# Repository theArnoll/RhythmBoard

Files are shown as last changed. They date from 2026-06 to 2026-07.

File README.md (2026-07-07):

Logo and name

English | [繁體中文 (Traditional Chinese)](./README_zhTW.md)

An easily customizable controller for most computer rhythm games.

Suitable for multiple games, including:

| | | | |
| - | - | - | - |
| osu! | DJMAX RESPECT V | Quaver | vivid/stasis |
| Milthm | Rhythm Doctor | Sparebeat | Polylylyrhythm |
| Estella | In Falsus (theoretically) | and more | |

The overall layout and default keymap are optimized for DJMAX RESPECT V and my own key binding, but any games similar to this are supported. You only need to edit the keymap in [ZMK Studio](https://zmk.studio/) to easily optimize the Rhythmboard for the game you're playing or your preferred key bindings.

<!-- TODO: Images and photos -->

## Table of Contents

- [Table of Contents](#table-of-contents)
- [Get Started](#get-started)
  - [Install Firmware](#install-firmware)
  - [Build from hardware](#build-from-hardware)
    - [BOM](#bom)
    - [1. Prepare and Print PCB](#1-prepare-and-print-pcb)
    - [2. Solder Everything](#2-solder-everything)
    - [3. Assembly](#3-assembly)
    - [4. Install Firmware](#4-install-firmware)
- [Default keymap](#default-keymap)
  - [Customize your keymap](#customize-your-keymap)
- [TODOs](#todos)

## Get Started

[Install Firmware](#install-firmware)  
[Building your own Rhythmboard from hardware](#build-from-hardware)  
[BOM](#bom)

### Install Firmware
<details>

<summary>If you're familiar with developing RP2040 microcontrollers or Raspberry Pi Pico, click here for a shorter explanation.</summary>

1. Go to the `Actions` tab.
2. Click the latest workflow run.
3. Find the `Artifacts` section, locate `firmware`, and click the download icon on the right to download `firmware.zip`.
   **If you can't find the `Artifacts` section**, click [here](https://github.com/theArnoll/RhythmBoard/actions/runs/28886995200/artifacts/8146596750).
4. Connect your board to your computer in BOOTSEL mode (by plugging in the RP2040-Zero while holding the BOOT button).
5. Unzip the `firmware.zip` you just downloaded and find the `.uf2` file inside.
6. Drag and drop the `.uf2` file into the RP2040-Zero USB drive (likely named `RPI-RP2`), and you're good to go.

---

</details>

1. Go to the `Actions` tab.
2. Click the latest workflow run.
3. Find the `Artifacts` section, locate `firmware`, and click the download icon on the right to download `firmware.zip`.
   **If you can't find the `Artifacts` section**, click [here](https://github.com/theArnoll/RhythmBoard/actions/runs/27891480540/artifacts/7771182646).
4. Press and hold the `BOOT` button on the RP2040-Zero. **DO NOT RELEASE** it before plugging the RP2040-Zero into your computer. Once plugged in, release the button. You should see a new USB device appear on your computer, likely named `RPI-RP2`.
5. Unzip the `firmware.zip` you just downloaded, locate the `.uf2` file in the extracted folder, and drag or copy it into the USB drive that appeared in the previous step.
6. Once the copy is complete, the USB drive will automatically disconnect, and the RP2040-Zero will reboot. Your Rhythmboard is now ready to use with the latest features available.

### Build from hardware

#### BOM

- RP2040-Zero x 1
- Machined Pin Header (23 pins in total: 9 pins x 2 + 5 pins)
- Machined Female Header (23 pins in total: 9 pins x 2 + 5 pins)
- MX profile mechanical switch hotswap socket x 17
- 1N4148W diode (SOD-123 package) x 17

- MX profile mechanical switch x 17
- Keycaps
  - 1u x 12
  - 1.25u x 1
  - 1.5u x 2
  - 2.25u x 2
- 2u PCB mount stabilizers x 2

#### 1. Prepare and Print PCB

1. Find the Gerber `.zip` file [here](/PCB/RhythmGameControllerKiCad/production/Gerber.zip).
2. Find a PCB manufacturer to make your PCB.
   [JLCPCB](https://jlcpcb.com/) is what I use and have tested. PCB Assembly (PCBA) is supported with the given files, but it might not be supported by other manufacturers. If you prefer other manufacturers and wish to use a PCBA service, please configure the necessary files yourself.
   *Not sponsored, but open to sponsorships from anyone (not limited to JLCPCB LOL).*
   > For the files required by JLCPCB PCBA: the BOM file is located at [/PCB/RhythmGameControllerKiCad/production/bom.csv](/PCB/RhythmGameControllerKiCad/production/bom.csv), and the placement/CPL file is located at [/PCB/RhythmGameControllerKiCad/production/positions.csv](/PCB/RhythmGameControllerKiCad/production/positions.csv).
3. Place your order and wait for your PCB to arrive.

#### 2. Solder Everything

Although I used a PCBA service for the SMD parts, if you are hand-soldering, it is recommended to solder the diodes first, followed by the switch sockets.

For THT parts, the workflow I chose is to solder the machined pin headers onto the RP2040-Zero first. Then, use the RP2040-Zero to confirm and adjust the angle before soldering the machined pin sockets onto the PCB.

#### 3. Assembly

1. Mount the stabilizers.
2. Mount the RP2040-Zero.
3. Place the switches.
4. Mount the keycaps. <!-- Note: add plate and case installation from here -->

#### 4. Install Firmware

Install the firmware onto your RP2040-Zero by following the steps written [here](#install-firmware).

## Default keymap

Check [here](https://gist.github.com/theArnoll/bf225b66670c3d527fa65544731ffbb3#file-layout-notes-md) for better visual effect

Layer 0 (default)
<table>
  <tr>
    <td width="12.5%" align="center">ESC</td>
    <td width="12.5%" align="center">ZMK<br>Studio</td>
    <td colspan="4"></td>
    <td width="12.5%" align="center">Alt+F9</td>
    <td width="12.5%" align="center">`</td>
  </tr>
  <tr>
    <td align="center">W</td>
    <td align="center">E</td>
    <td align="center">R</td>
    <td align="center">T</td>
    <td align="center">U</td>
    <td align="center">I</td>
    <td align="center">O</td>
    <td align="center">P</td>
  </tr>
  <tr>
    <td colspan="3"></td>
    <td align="center">G</td>
    <td align="center">J</td>
    <td></td>
    <td colspan="2" rowspan="2"></td>
  </tr>
  <tr>
    <td align="center">to 1</td>
    <td></td>
    <td colspan="2" align="center">G</td>
    <td colspan="2" align="center">J</td>
  </tr>
</table>

Layer 1
<table>
  <tr>
    <td width="12.5%" align="center">1</td>
    <td width="12.5%" align="center">ZMK<br>Studio</td>
    <td colspan="4"></td>
    <td width="12.5%" align="center">to 3</td>
    <td width="12.5%" align="center">2</td>
  </tr>
  <tr>
    <td align="center">F10</td>
    <td align="center">L⇧</td>
    <td align="center">↑</td>
    <td align="center">↓</td>
    <td align="center">←</td>
    <td align="center">→</td>
    <td align="center">R⇧</td>
    <td align="center">F11</td>
  </tr>
  <tr>
    <td colspan="3"></td>
    <td align="center">A</td>
    <td align="center">↹</td>
    <td></td>
    <td colspan="2" rowspan="2"></td>
  </tr>
  <tr>
    <td align="center">to 1</td>
    <td></td>
    <td colspan="2" align="center">␣</td>
    <td colspan="2" align="center">↵</td>
  </tr>
</table>

<details>
<summary> Layer 2 (Layer transportation) </summary>
<table>
  <tr>
    <td width="12.5%" align="center">to 0</td>
    <td width="12.5%" align="center">to 1</td>
    <td colspan="4"></td>
    <td width="12.5%" align="center">to 0</td>
    <td width="12.5%" align="center">to 0</td>
  </tr>
  <tr>
    <td align="center">to 3</td>
    <td align="center">to 4</td>
    <td align="center">to 5</td>
    <td align="center">to 6</td>
    <td align="center">to 7</td>
    <td align="center">to 8</td>
    <td align="center">to 9</td>
    <td align="center">to 10</td>
  </tr>
  <tr>
    <td colspan="3"></td>
    <td align="center">none</td>
    <td align="center">none</td>
    <td></td>
    <td colspan="2" rowspan="2"></td>
  </tr>
  <tr>
    <td align="center">to 0</td>
    <td></td>
    <td colspan="2" align="center">none</td>
    <td colspan="2" align="center">none</td>
  </tr>
</table>
</details>

<details>
<summary> Layer 3 (QWERTY DFJK default layout that's the default for most games) </summary>
<table>
  <tr>
    <td width="12.5%" align="center">ESC</td>
    <td width="12.5%" align="center">none</td>
    <td colspan="4"></td>
    <td width="12.5%" align="center">ALT+F9</td>
    <td width="12.5%" align="center">`</td>
  </tr>
  <tr>
    <td align="center">A</td>
    <td align="center">S</td>
    <td align="center">D</td>
    <td align="center">F</td>
    <td align="center">J</td>
    <td align="center">K</td>
    <td align="center">L</td>
    <td align="center">;</td>
  </tr>
  <tr>
    <td colspan="3"></td>
    <td align="center">V</td>
    <td align="center">N</td>
    <td></td>
    <td colspan="2" rowspan="2"></td>
  </tr>
  <tr>
    <td align="center">to 1</td>
    <td></td>
    <td colspan="2" align="center">V</td>
    <td colspan="2" align="center">N</td>
  </tr>
</table>
</details>

<details>
<summary> Layer 4 (Hotkeys pad) </summary>
<table>
  <tr>
    <td width="12.5%" align="center">ESC</td>
    <td width="12.5%" align="center">none</td>
    <td colspan="4"></td>
    <td width="12.5%" align="center">ALT+F9</td>
    <td width="12.5%" align="center">`</td>
  </tr>
  <tr>
    <td align="center">A</td>
    <td align="center">X</td>
    <td align="center">C</td>
    <td align="center">V</td>
    <td align="center">Z</td>
    <td align="center">N</td>
    <td align="center">HOME</td>
    <td align="center">END</td>
  </tr>
  <tr>
    <td colspan="3"></td>
    <td align="center">LALT</td>
    <td align="center">LGUI</td>
    <td></td>
    <td colspan="2" rowspan="2"></td>
  </tr>
  <tr>
    <td align="center">to 2</td>
    <td></td>
    <td colspan="2" align="center">LCTRL</td>
    <td colspan="2" align="center">LSHIFT</td>
  </tr>
</table>
</details>

<details>
<summary> Layer 5~10 (user define) </summary>
<table>
  <tr>
    <td width="12.5%" align="center">ESC</td>
    <td width="12.5%" align="center">none</td>
    <td colspan="4"></td>
    <td width="12.5%" align="center">ALT+F9</td>
    <td width="12.5%" align="center">`</td>
  </tr>
  <tr>
    <td align="center">W</td>
    <td align="center">E</td>
    <td align="center">R</td>
    <td align="center">T</td>
    <td align="center">U</td>
    <td align="center">I</td>
    <td align="center">O</td>
    <td align="center">P</td>
  </tr>
  <tr>
    <td colspan="3"></td>
    <td align="center">G</td>
    <td align="center">J</td>
    <td></td>
    <td colspan="2" rowspan="2"></td>
  </tr>
  <tr>
    <td align="center">to 1</td>
    <td></td>
    <td colspan="2" align="center">G</td>
    <td colspan="2" align="center">J</td>
  </tr>
</table>
</details>

### Customize your keymap

1. Press the "ZMK Studio" key.
2. Go to [ZMK Studio](https://zmk.studio/).
3. Your browser may display a COM port connection pop-up (at least Chromium-based browsers do). Select the COM port your Rhythmboard is connected to. (It's not going to be COM1 or COM2 on Windows).
4. Customize your key bindings, keymaps, and layers on ZMK Studio as you want.
   > ⚠️ Note: Wireless-related options are not supported.

## TODOs
<!-- TODO: -->
- Upload plate file 
- Create its case <!-- Note: Need to edit #### 3. Assembly after uploaded -->

---

Developed based on [theArnoll/ZMK-4x3-Keyboard](https://github.com/theArnoll/ZMK-4x3-Keyboard)

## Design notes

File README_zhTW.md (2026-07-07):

Logo and name

[English](README.md) | 繁體中文  
> 內容使用 Google AI Studio 上的 gemma-4-26b-a4b-it 進行翻譯以提高開發效率  
> 中文內容可能為非最新版本，請以英文版本為準

一款適用於大多數電腦節奏遊戲、易於自定義的控制器。

支援多款遊戲，包括：

| | | | |
| - | - | - | - |
| osu! | DJMAX RESPECT V | Quaver | vivid/stasis |
| Milthm | 節奏醫生 | Sparebeat | Polylylyrhythm |
| Estella | In Falsus (理論上) | 更多 | |

整體佈局與預設按鍵配置已針對 DJMAX RESPECT V 與個人按鍵配置進行優化，但也支援任何類似款式的遊戲。您只需要在 [ZMK Studio](https://zmk.studio/) 中編輯按鍵配置，即可輕鬆針對您正在玩的遊戲或個人偏好的按鍵綁定進行優化。

<!-- TODO: 圖片與照片 -->

## 目錄

- [目錄](#目錄)
- [快速上手](#快速上手)
  - [安裝韌體](#安裝韌體)
  - [從硬體開始組裝](#從硬體開始組裝)
    - [物料清單 (BOM)](#物料清單-bom)
    - [1. 準備並列印 PCB](#1-準備並列印-pcb)
    - [2. 焊接所有組件](#2-焊接所有組件)
    - [3. 組裝](#3-組裝)
    - [4. 安裝 ZMK 韌體](#4-安裝-zmk-韌體)
- [預設按鍵配置](#預設按鍵配置)
  - [自定您的按鍵配置](#自定您的按鍵配置)
- [待辦事項](#待辦事項)

## 快速上手

[安裝韌體](#install-firmware)  
[從硬體開始組裝您的 Rhythmboard](#build-from-hardware)  
[物料清單 (BOM)](#bom)

### 安裝韌體
<details>

<summary>如果您熟悉 RP2040 微控制器或 Raspberry Pi Pico 的開發，請點擊此處查看簡短說明。</summary>

1. 前往 `Actions` 分頁。
2. 點擊最新的 workflow 執行紀錄。
3. 找到 `Artifacts` 區塊，找到 `firmware`，並點擊右側的下載圖示來下載 `firmware.zip`。
   **如果您找不到 `Artifacts` 區塊**，請點擊 [這裡](https://github.com/theArnoll/RhythmBoard/actions/runs/28886995200/artifacts/8146596750)。
4. 將您的板子以 BOOTSEL 模式連接到電腦（按住 BOOT 鍵的同時插入 RP2040-Zero）。
5. 解壓縮剛下載的 `firmware.zip` 並找到裡面的 `.uf2` 檔案。
6. 將 `.uf2` 檔案拖放至 RP2040-Zero 的 USB 磁碟機中（名稱通常為 `RPI-RP2`），即可完成。

---

</details>

1. 前往 `Actions` 分頁。
2. 點擊最新的 workflow 執行紀錄。
3. 找到 `Artifacts` 區塊，找到 `firmware`，並點擊右側的下載圖示來下載 `firmware.zip`。
   **如果您找不到 `Artifacts` 區塊**，請點擊 [這裡](https://github.com/theArnoll/RhythmBoard/actions/runs/27726159548/artifacts/7710387346)。
4. 按住 RP2040-Zero 上的 `BOOT` 按鈕。**在將 RP2040-Zero 插入電腦之前請勿放開**。插入後再放開按鈕。您應該會在電腦上看到一個新的 USB 裝置出現，名稱通常為 `RPI-RP2`。
5. 解壓縮剛下載的 `firmware.zip`，在解壓縮後的資料夾中找到 `.uf2` 檔案，並將其拖入或複製到上一步出現的 USB 磁碟機中。
6. 複製完成後，USB 磁碟機會自動斷開連接，RP2040-Zero 將會重新啟動。您的 Rhythmboard 現在已可以使用最新的功能。

### 從硬體開始組裝

#### 物料清單 (BOM)

- RP2040-Zero x 1
- 針型排針 (Machined Pin Header) (共 23 Pin：9 Pin x 2 + 5 Pin)
- 針型排母 (Machined Female Header) (共 23 Pin：9 Pin x 2 + 5 Pin)
- MX profile 機械軸熱插拔底座 (hotswap socket) x 17
- 1N4148W 二極體 (SOD-123 封裝) x 17

- MX profile 機械軸 x 17
- 鍵帽
  - 1u x 12
  - 1.25u x 1
  - 1.5u x 2
  - 2.25u x 2
- 2u PCB 固定式平衡桿 (stabilizers) x 2

#### 1. 準備並列印 PCB

1. 在[這裡](/PCB/RhythmGameControllerKiCad/production/Gerber.zip)找到 Gerber `.zip` 檔案。
2. 找一家 PCB 製造商來製作您的 PCB。
   我個人使用的是 [JLCPCB](https://jlcpcb.com/) 並經過測試。提供的檔案支援 PCB 組件加工 (PCBA)，但其他製造商可能不支援。如果您偏好其他製造商並希望使用 PCBA 服務，請自行配置必要的檔案。
   *本專案並非贊助內容，但歡迎任何人的贊助 (不限於 JLCPCB 喔 LOL)。*
   > 若需 JLCPCB PCBA 所需的檔案：BOM 檔案位於 [/PCB/RhythmGameControllerKiCad/production/bom.csv](/PCB/RhythmGameControllerKiCad/production/bom.csv)，元件位置 (CPL) 檔案位於 [/PCB/RhythmGameControllerKiCad/production/positions.csv](/PCB/RhythmGameControllerKiCad/production/positions.csv)。
3. 下單並等待您的 PCB 送達。

#### 2. 焊接所有組件

雖然我使用了 PCBA 服務來處理 SMD (表面黏著) 零件，但如果您是手動焊接，建議先焊接二極體，接著再焊接軸座。

對於 THT (通孔) 零件，我選擇的工作流程是先將針型排針焊接在 RP2040-Zero 上。接著，利用 RP2040-Zero 來確認並調整角度，然後再將針型排母焊接在 PCB 上。

#### 3. 組裝

1. 安裝平衡桿。
2. 安裝 RP2040-Zero。
3. 安裝軸體。
4. 安裝鍵帽。 <!-- 註：待上傳後需在此添加定位板與外殼安裝說明 -->

#### 4. 安裝 ZMK 韌體

請依照[這裡](#安裝韌體)所寫的步驟將韌體安裝到您的 RP2040-Zero。

## 預設按鍵配置

[here](https://gist.github.com/theArnoll/bf225b66670c3d527fa65544731ffbb3#file-layout-notes-md) 有更好的視覺效果的版本

層次 0 (預設)
<table>
  <tr>
    <td width="12.5%" align="center">ESC</td>
    <td width="12.5%" align="center">ZMK<br>Studio</td>
    <td colspan="4"></td>
    <td width="12.5%" align="center">Alt+F9</td>
    <td width="12.5%" align="center">`</td>
  </tr>
  <tr>
    <td align="center">W</td>
    <td align="center">E</td>
    <td align="center">R</td>
    <td align="center">T</td>
    <td align="center">U</td>
    <td align="center">I</td>
    <td align="center">O</td>
    <td align="center">P</td>
  </tr>
  <tr>
    <td colspan="3"></td>
    <td align="center">G</td>
    <td align="center">J</td>
    <td></td>
    <td colspan="2" rowspan="2"></td>
  </tr>
  <tr>
    <td align="center">to 1</td>
    <td></td>
    <td colspan="2" align="center">G</td>
    <td colspan="2" align="center">J</td>
  </tr>
</table>

層次 1
<table>
  <tr>
    <td width="12.5%" align="center">1</td>
    <td width="12.5%" align="center">ZMK<br>Studio</td>
    <td colspan="4"></td>
    <td width="12.5%" align="center">to 3</td>
    <td width="12.5%" align="center">2</td>
  </tr>
  <tr>
    <td align="center">F10</td>
    <td align="center">L⇧</td>
    <td align="center">↑</td>
    <td align="center">↓</td>
    <td align="center">←</td>
    <td align="center">→</td>
    <td align="center">R⇧</td>
    <td align="center">F11</td>
  </tr>
  <tr>
    <td colspan="3"></td>
    <td align="center">A</td>
    <td align="center">↹</td>
    <td></td>
    <td colspan="2" rowspan="2"></td>
  </tr>
  <tr>
    <td align="center">to 1</td>
    <td></td>
    <td colspan="2" align="center">␣</td>
    <td colspan="2" align="center">↵</td>
  </tr>
</table>

<details>
<summary> 層次 2 (層次切換) </summary>
<table>
  <tr>
    <td width="12.5%" align="center">to 0</td>
    <td width="12.5%" align="center">to 1</td>
    <td colspan="4"></td>
    <td width="12.5%" align="center">to 0</td>
    <td width="12.5%" align="center">to 0</td>
  </tr>
  <tr>
    <td align="center">to 3</td>
    <td align="center">to 4</td>
    <td align="center">to 5</td>
    <td align="center">to 6</td>
    <td align="center">to 7</td>
    <td align="center">to 8</td>
    <td align="center">to 9</td>
    <td align="center">to 10</td>
  </tr>
  <tr>
    <td colspan="3"></td>
    <td align="center">none</td>
    <td align="center">none</td>
    <td></td>
    <td colspan="2" rowspan="2"></td>
  </tr>
  <tr>
    <td align="center">to 0</td>
    <td></td>
    <td colspan="2" align="center">none</td>
    <td colspan="2" align="center">none</td>
  </tr>
</table>
</details>

<details>
<summary> 層次 3 (QWERTY DFJK 預設佈局，多數遊戲的標準配置) </summary>
<table>
  <tr>
    <td width="12.5%" align="center">ESC</td>
    <td width="12.5%" align="center">none</td>
    <td colspan="4"></td>
    <td width="12.5%" align="center">ALT+F9</td>
    <td width="12.5%" align="center">`</td>
  </tr>
  <tr>
    <td align="center">A</td>
    <td align="center">S</td>
    <td align="center">D</td>
    <td align="center">F</td>
    <td align="center">J</td>
    <td align="center">K</td>
    <td align="center">L</td>
    <td align="center">;</td>
  </tr>
  <tr>
    <td colspan="3"></td>
    <td align="center">V</td>
    <td align="center">N</td>
    <td></td>
    <td colspan="2" rowspan="2"></td>
  </tr>
  <tr>
    <td align="center">to 1</td>
    <td></td>
    <td colspan="2" align="center">V</td>
    <td colspan="2" align="center">N</td>
  </tr>
</table>
</details>

<details>
<summary> 層次 4 (快捷鍵墊) </summary>
<table>
  <tr>
    <td width="12.5%" align="center">ESC</td>
    <td width="12.5%" align="center">none</td>
    <td colspan="4"></td>
    <td width="12.5%" align="center">ALT+F9</td>
    <td width="12.5%" align="center">`</td>
  </tr>
  <tr>
    <td align="center">A</td>
    <td align="center">X</td>
    <td align="center">C</td>
    <td align="center">V</td>
    <td align="center">Z</td>
    <td align="center">N</td>
    <td align="center">HOME</td>
    <td align="center">END</td>
  </tr>
  <tr>
    <td colspan="3"></td>
    <td align="center">LALT</td>
    <td align="center">LGUI</td>
    <td></td>
    <td colspan="2" rowspan="2"></td>
  </tr>
  <tr>
    <td align="center">to 2</td>
    <td></td>
    <td colspan="2" align="center">LCTRL</td>
    <td colspan="2" align="center">LSHIFT</td>
  </tr>
</table>
</details>

<details>
<summary> 層次 5~10 (使用者定義) </summary>
<table>
  <tr>
    <td width="12.5%" align="center">ESC</td>
    <td width="12.5%" align="center">none</td>
    <td colspan="4"></td>
    <td width="12.5%" align="center">ALT+F9</td>
    <td width="12.5%" align="center">`</td>
  </tr>
  <tr>
    <td align="center">W</td>
    <td align="center">E</td>
    <td align="center">R</td>
    <td align="center">T</td>
    <td align="center">U</td>
    <td align="center">I</td>
    <td align="center">O</td>
    <td align="center">P</td>
  </tr>
  <tr>
    <td colspan="3"></td>
    <td align="center">G</td>
    <td align="center">J</td>
    <td></td>
    <td colspan="2" rowspan="2"></td>
  </tr>
  <tr>
    <td align="center">to 1</td>
    <td></td>
    <td colspan="2" align="center">G</td>
    <td colspan="2" align="center">J</td>
  </tr>
</table>
</details>

### 自定您的按鍵配置

1. 按下「ZMK Studio」鍵。
2. 前往 [ZMK Studio](https://zmk.studio/)。
3. 您的瀏覽器可能會顯示 COM 埠連接彈出視窗（至少基於 Chromium 的瀏覽器會顯示）。請選擇您的 Rhythmboard 所連接的 COM 埠。（在 Windows 上通常不會是 COM1 或 COM2）。
4. 依照您的需求，在 ZMK Studio 上自定義按鍵綁定、按鍵配置與層次。
   > ⚠️ 注意：目前不支援無線相關選項。

## 待辦事項
<!-- TODO: -->
- 上傳定位板檔案
- 設計外殼 <!-- 註：檔案上傳後需修改 #### 3. 組裝 部分 -->

---

基於 [theArnoll/ZMK-4x3-Keyboard](https://github.com/theArnoll/ZMK-4x3-Keyboard) 開發。

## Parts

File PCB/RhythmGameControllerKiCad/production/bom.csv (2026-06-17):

Designator | Footprint | Quantity | Value | LCSC Part #
DIODE<_17, DIODE<_16, DIODE<_15, DIODE<_14, DIODE<_13, DIODE<_12, DIODE<_11, DIODE<_10, DIODE<_9, DIODE<_8, DIODE<_7, DIODE<_6, DIODE<_5, DIODE<_4, DIODE<_3, DIODE<_2, DIODE< | D_SOD-123F | 17 | D_SOD-123F | C81598
REFMX_17, REFMX_16 | MX_Hotswap_2.25u | 2 | MX_2.25u_PG151101S11 | C49352235
REFMX_15, REFMX_14, REFMX_13, REFMX_12, REFMX_10, REFMX_9, REFMX_8, REFMX_5, REFMX_4, REFMX_3, REFMX_2, REFMX | MX_Hotswap_1.00u | 12 | MX_1.00u_PG151101S11 | C49352235
REFMX_11 | MX_Hotswap_1.25u | 1 | MX_1.25u_PG151101S11 | C49352235
REFMX_7, REFMX_6 | MX_Hotswap_1.50u | 2 | MX_1.50u_PG151101S11 | C49352235

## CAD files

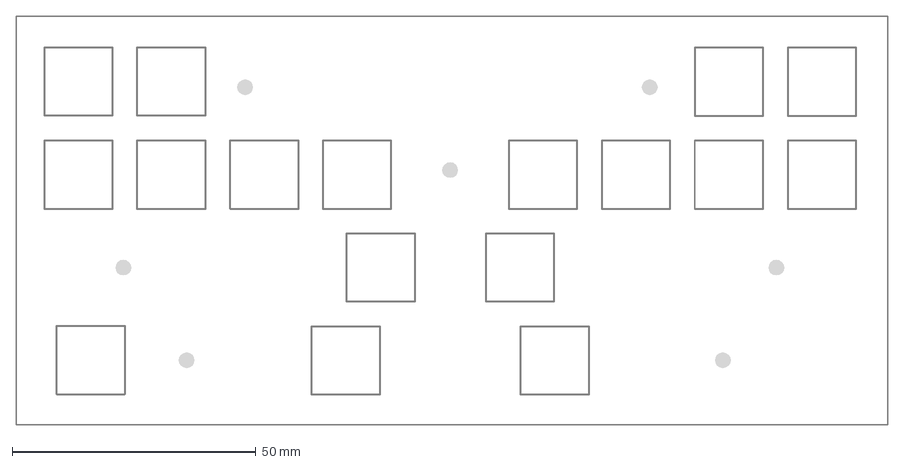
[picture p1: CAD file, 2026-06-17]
PCB/RhythmGameControllerKiCad/Plate_DXF/RhythmGameControllerKiCad_Plate-Edge_Cuts.dxf
178.9 x 83.9 mm

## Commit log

2026-05-30 Reselect program wise board as RPi Pico
2026-05-30 Changing the pin choice since real Pico doesn't have Pin 29
2026-05-30 Fix USB Conflict and try bringing pin 29 back
2026-05-30 Fix diode direction
2026-05-30 Modifying diode direction and transform map
2026-05-30 Modify didode direction, col/row pin set and active status
2026-05-30 Modify diode direction
2026-05-30 change diode direction & pull up pin
2026-06-17 Upload PCB and edit keymap
    [RhythmGameControllerKiCad-B_Cu.gbr, RhythmGameControllerKiCad-B_Mask.gbr, RhythmGameControllerKiCad-B_Paste.gbr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]
